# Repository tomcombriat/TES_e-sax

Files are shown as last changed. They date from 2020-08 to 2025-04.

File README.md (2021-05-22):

# TES - e-sax

More infos: https://t-e-s.frama.site/en/tesaxophone

The E-sax is an EWI made out of a real sax. It outputs MIDI signals that can be used to generate sounds using a synthesizer for instance the [10k synth](https://github.com/tomcombriat/TES_10-knobs-synth). It is design to provide saxophone players a digital instrument to which they can transition easily. Additionnaly from the "standard" behavior it also have features that are allowed by a digital instrument:

- EWI mode which tries to give a more ergonomic keying (E mode)
- chords (C mode)
- arpegiators (A and R modes)

## What is in this repo?
The [hardware](hardware/) folder contains the kicad project for the PCB used in the e-sax alongside with the Cu and Fab masks. It is single sided in order to make its construction possible for an hobbyist. Note that the isolations and the routes are fairly small (around 200 microns) so you will need to have a fairly optimized setup to be able to make this PCB correctly.

The [software](software/) folder contains the embedded program that is embedded in the chip. Note that it will need some configurations for any particular saxophone.

The main MCU is a cheap BluePill STM32, programmed using the [Arduino STM32 library](https://github.com/stm32duino/Arduino_Core_STM32) and a FTDI.

## Making
This gives some guidelines in order to allow people to make such an E-sax themselves. It precludes that the PCB is already printed and drilled.

Note: no 3D parts are included in this repo for now. Except for the beak, every part usually need to be redesigned for a different saxophone. Do not hesitate to contact me on that.

### Bill of Materials 

- 24 resistors 1-10k, noted R on the PCB
- 1 resistor 33
- 2 resistors 22k (optionnal)
- 1 resistor 10
- 1 BluePill
- 1 FTDI chip to program the BluePill
- 3 74HC165 Parallel-to-Serial shift registers
- enough header
- 1 SSD1306 Oled screen (*I2C*)
- 1 MPX5010 differential pressure sensor
- 1 joystick with a click
- a good amount of flexible thin wire (around 26 AWG, silicon cover)
- Dupond cables
- a good amount of copper tape
- 1 3-AA battery holder
- 1 MIDI female to solder
- 1 switch (non-momentary)
- 2 pairs (male and female) of JST connectors 3 pins
- 1 pair of JST connectors 5 pins
- 10 magnets (10x4x2mm^3) (optionnal)

### Wiring the saxophone

The controller needs to know what keys are pressed at any given time in order to be able to generate the correct MidiNote for a synthesizer. In order for the behavior to be as close as possible to a real saxophone, the sensors are positionned on the pads and not on the keys: if a key closing a pad is not pressed enough to close the pad the controller will consider it "open" just like it would be for a real saxophone. All the wires for the pads are going through the sax body.

The saxophone is a complex instrument and not every pad can be dismounted "alone": it is usual that some of them need other to be removed first in order to be dismounted.

#### Dismounting
This is why it is usually easier to dismount all the keys first and wire them on remounting.
Note: take some notes about which keys did you dismounted first: as the order matters they will need to be remounted in the _reverse order_. My personnal way of doing it is to write on every part a number and a letter (the latter only if this is a pad): the number denotes the order of dismounting (first dismounted part will be labelled "1", second "2"…) and the letter denotes the hole the pad is covering. I also write the same letter next to, or in, the hole which is covered by the pad. This way, upon remounting, one can start by the part with highest number, spot its hole (if any) and remount it.

#### Wiring the pads

The pads can be wired upon remounting. All pads need to be wired except the one which is just above the left hand forefinger which is not independant from the pad located under the left hand forefinger.

The sensor is composed of a thin copper layer glued to the pad and wire to the PCB. Using a push-up resistor, and by placing the whole sax body at GND the pad will behave as a switch:

- closed, the potential of the copper part will be at GND as it is in contact with the body
- open, the potential will be at 3.3V, thanks to a push-up resistor.

The copper tape needs to be glued to the pad:

- cut a piece of copper tape that matches more or less the dimension of the pad. The exact size of this piece is not critical but:
  - it need to cover some of the parts of the pad which are in contact with the body when closed. If possible at two different locations meaning that the length of this copper part should be at least be equal to the diameter of the hole covered by the pad.
  - it should not be too long either in order not to touch the metallic part of the key.
- apply a thin layer of neopren glue on the **tape** side of the copper, it should cover it all. Beware not to put some glue on the "clear" part of the copper
- apply a thin layer of neopren on the pad, it should match the dimensions of the piece of copper.
- wait from 10 to 15 minutes
- apply the copper, glue side of the tape facing the glue side of the pad, it should stick immediatly so the first attempt should be well positionned.
- using a soldering iron, add some solder at **the middle of the pad**, it should not touch the part where the pad touches the body.
- soldier a flexible wire long enough to go from the corresponding hole to the bell plus 5cm to it.
- put the wire in the hole and make it go to the bell throught the body (this can be hard for some keys) and tape it to the bell.
- remount the key on its hole.
- if done correctly, the key should action seemlessly and feel as natural as before.
- start again for all the other keys.

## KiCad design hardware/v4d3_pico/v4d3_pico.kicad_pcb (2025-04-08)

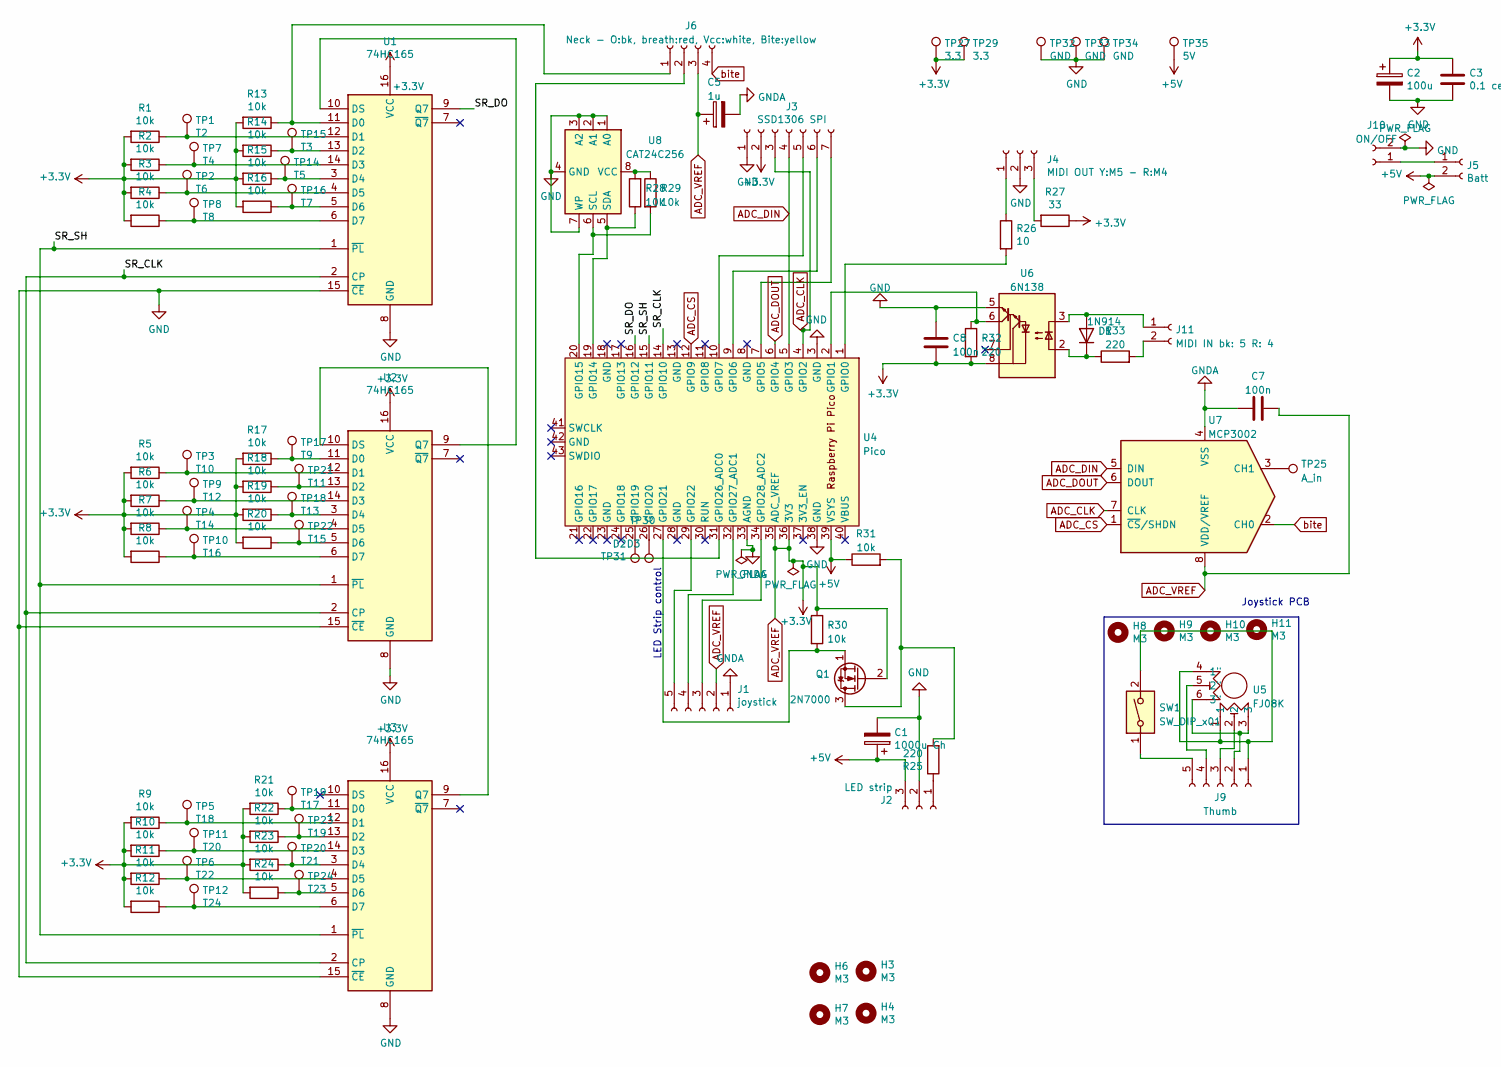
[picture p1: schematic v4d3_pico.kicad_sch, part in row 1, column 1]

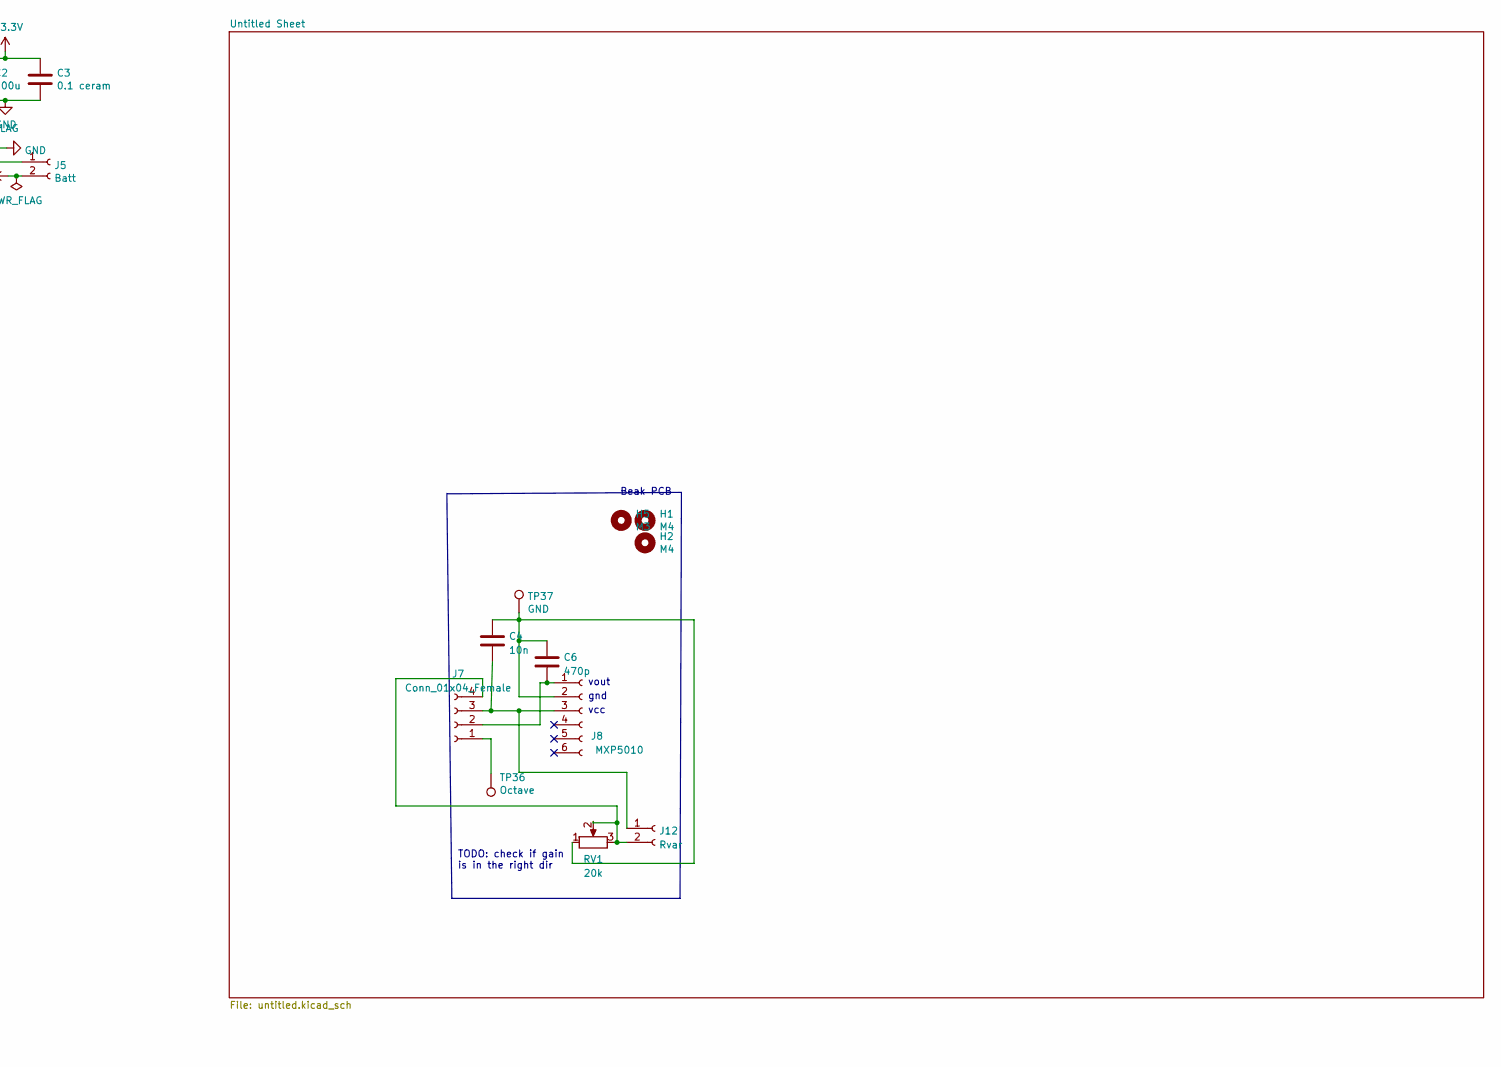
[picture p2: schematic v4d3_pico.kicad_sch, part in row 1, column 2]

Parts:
C1: 1000u Ch; CP_Radial_D8.0mm_P3.50mm
C2: 100u; CP_Radial_D5.0mm_P2.50mm
C3: 0.1 ceram; C_Disc_D3.4mm_W2.1mm_P2.50mm
C4: 10n; C_Disc_D3.4mm_W2.1mm_P2.50mm
C5: 1u; CP_Radial_D4.0mm_P2.00mm
C6: 470p; C_Disc_D3.4mm_W2.1mm_P2.50mm
C7, C8: 100n; C_Axial_L3.8mm_D2.6mm_P7.50mm_Horizontal
D1: 1N914; D_DO-34_SOD68_P7.62mm_Horizontal
H1, H2: M4; MountingHole_4.3mm_M4
H3, H4, H5, H6, H7, H8, H9, H10, H11: M3; MountingHole_3.2mm_M3_ISO14580
J1: joystick; JST_PH_B5B-PH-K_1x05_P2.00mm_Vertical
J2: LED strip; JST_PH_S3B-PH-K_1x03_P2.00mm_Horizontal
J3: SSD1306 SPI; JST_PH_B7B-PH-K_1x07_P2.00mm_Vertical
J4: MIDI OUT Y:M5 - R:M4; JST_PH_S3B-PH-K_1x03_P2.00mm_Horizontal
J5: Batt; JST_XH_S2B-XH-A_1x02_P2.50mm_Horizontal
J6: Neck - O:bk, breath:red, Vcc:white, Bite:yellow; JST_PH_B4B-PH-K_1x04_P2.00mm_Vertical
J7: Conn_01x04_Female; JST_PH_B4B-PH-K_1x04_P2.00mm_Vertical
J8: MXP5010; PinSocket_1x06_P2.54mm_Vertical
J9: Thumb; JST_PH_S5B-PH-K_1x05_P2.00mm_Horizontal
J10: ON/OFF; JST_XH_S2B-XH-A_1x02_P2.50mm_Horizontal
J11: MIDI IN bk: 5 R: 4; JST_XH_S2B-XH-A_1x02_P2.50mm_Horizontal
J12: Rvar; JST_XH_B2B-XH-A_1x02_P2.50mm_Vertical
Q1: 2N7000; TO-92L_HandSolder
R1, R2, R3, R4, R5, R6, R7, R8, R9, R10, R11, R12, R13, R14, R15, R16, R17, R18, R19, R20, R21, R22, R23, R24, R28, R29, R30: 10k; R_1206_3216Metric_Pad1.30x1.75mm_HandSolder
R25, R32, R33: 220; R_Axial_DIN0207_L6.3mm_D2.5mm_P7.62mm_Horizontal
R26: 10; R_Axial_DIN0207_L6.3mm_D2.5mm_P7.62mm_Horizontal
R27: 33; R_Axial_DIN0207_L6.3mm_D2.5mm_P7.62mm_Horizontal
R31: 10k; R_Axial_DIN0207_L6.3mm_D2.5mm_P7.62mm_Horizontal
RV1: 20k; Potentiometer_Runtron_RM-065_Vertical
SW1: SW_DIP_x01; Multi_switch
TP1: T2; TestPoint_THTPad_2.5x2.5mm_Drill1.2mm
TP2: T6; TestPoint_THTPad_2.5x2.5mm_Drill1.2mm
TP3: T10; TestPoint_THTPad_2.5x2.5mm_Drill1.2mm
TP4: T14; TestPoint_THTPad_2.5x2.5mm_Drill1.2mm
TP5: T18; TestPoint_THTPad_2.5x2.5mm_Drill1.2mm
TP6: T22; TestPoint_THTPad_2.5x2.5mm_Drill1.2mm
TP7: T4; TestPoint_THTPad_2.5x2.5mm_Drill1.2mm
TP8: T8; TestPoint_THTPad_2.5x2.5mm_Drill1.2mm
TP9: T12; TestPoint_THTPad_2.5x2.5mm_Drill1.2mm
TP10: T16; TestPoint_THTPad_2.5x2.5mm_Drill1.2mm
TP11: T20; TestPoint_THTPad_2.5x2.5mm_Drill1.2mm
TP12: T24; TestPoint_THTPad_2.5x2.5mm_Drill1.2mm
TP14: T5; TestPoint_THTPad_2.5x2.5mm_Drill1.2mm
TP15: T3; TestPoint_THTPad_2.5x2.5mm_Drill1.2mm
TP16: T7; TestPoint_THTPad_2.5x2.5mm_Drill1.2mm
TP17: T9; TestPoint_THTPad_2.5x2.5mm_Drill1.2mm
TP18: T13; TestPoint_THTPad_2.5x2.5mm_Drill1.2mm
TP19: T17; TestPoint_THTPad_2.5x2.5mm_Drill1.2mm
TP20: T21; TestPoint_THTPad_2.5x2.5mm_Drill1.2mm
TP21: T11; TestPoint_THTPad_2.5x2.5mm_Drill1.2mm
TP22: T15; TestPoint_THTPad_2.5x2.5mm_Drill1.2mm
TP23: T19; TestPoint_THTPad_2.5x2.5mm_Drill1.2mm
TP24: T23; TestPoint_THTPad_2.5x2.5mm_Drill1.2mm
TP25: A_in; TestPoint_THTPad_2.5x2.5mm_Drill1.2mm
TP27, TP29: 3.3; TestPoint_THTPad_2.5x2.5mm_Drill1.2mm
TP30: D3; TestPoint_THTPad_2.5x2.5mm_Drill1.2mm
TP31: D2; TestPoint_THTPad_2.5x2.5mm_Drill1.2mm
TP32, TP33, TP34, TP37: GND; TestPoint_THTPad_2.5x2.5mm_Drill1.2mm
TP35: 5V; TestPoint_THTPad_2.5x2.5mm_Drill1.2mm
TP36: Octave; TestPoint_THTPad_2.5x2.5mm_Drill1.2mm
U1, U2, U3: 74HC165; SOIC-16_3.9x9.9mm_P1.27mm
U4: Pico; RPi_Pico_TH
U5: FJ08K
U6: 6N138; DIP-8_W7.62mm_Socket
U7: MCP3002; DIP-8_W7.62mm
U8: CAT24C256; DIP-8_W7.62mm_Socket

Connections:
+5V: C1.1, J2.3, J5.2, R31.1, TP35.1, U4.39 (VSYS)
/SR_CLK: U1.2 (CP), U2.2 (CP), U3.2 (CP), U4.14 (GPIO10)
/SR_DO: U1.9 (Q7), U4.16 (GPIO12)
/SR_SH: U1.1 (~PL), U2.1 (~PL), U3.1 (~PL), U4.15 (GPIO11)
ADC_CLK: J3.3, U4.4 (GPIO2), U7.7 (CLK)
ADC_CS: U4.12 (GPIO9), U7.1 (~CS/SHDN)
ADC_DIN: J3.4, U4.5 (GPIO3), U7.5 (DIN)
ADC_DOUT: U4.6 (GPIO4), U7.6 (DOUT)
ADC_VREF: C2.1, C3.1, C5.1, C7.2, C8.2, J1.2, J3.2, J6.3, Q1.2 (G), R1.2, R2.2, R3.2, R4.2, R5.2, R6.2, R7.2, R8.2, R9.2, R10.2, R11.2, R12.2, R13.2, R14.2, R15.2, R16.2, R17.2, R18.2, R19.2, R20.2, R21.2, R22.2, R23.2, R24.2, R27.1, R30.1, R32.2, TP27.1, TP29.1, U1.16 (VCC), U2.16 (VCC), U3.16 (VCC), U4.35 (ADC_VREF), U4.36 (3V3), U6.8 (VCC), U7.8 (VDD/VREF)
GND: C1.2, C2.2, C3.2, C8.1, J2.2, J3.1, J4.2, J10.2, TP32.1, TP33.1, TP34.1, U1.8 (GND), U1.15 (~CE), U2.8 (GND), U2.15 (~CE), U3.8 (GND), U3.15 (~CE), U4.3 (GND), U4.38 (GND), U6.5 (GND), U8.1 (A0), U8.2 (A1), U8.3 (A2), U8.4 (GND), U8.7 (WP)
GNDA: C5.2, C7.1, J1.1, U4.33 (AGND), U7.4 (VSS)
unnamed: C4.2, J7.3, J8.3, J12.1
unnamed: C6.2, J7.2, J8.1
unnamed: D1.1 (K), R33.1, U6.2 (C1)
unnamed: D1.2 (A), J11.1, U6.3 (C2)
unnamed: J1.3, U4.34 (GPIO28_ADC2)
unnamed: J1.4, U4.32 (GPIO27_ADC1)
unnamed: J1.5, U4.29 (GPIO22)
unnamed: J2.1, R25.1
unnamed: J3.5, U4.10 (GPIO7)
unnamed: J3.6, U4.9 (GPIO6)
unnamed: J3.7, U4.7 (GPIO5)
unnamed: J4.1, R26.1
unnamed: J4.3, R27.2
unnamed: J6.1, R13.1, U1.11 (D0)
unnamed: J6.2, U4.31 (GPIO26_ADC0)
unnamed: J7.1, TP36.1
unnamed: J9.1, SW1.2, U5.1, U5.4 (1")
unnamed: J9.2, U5.3, U5.6 (3")
unnamed: J9.3, U5.2
unnamed: J9.4, U5.5 (2")
unnamed: J9.5, SW1.1
unnamed: J5.1, J10.1
unnamed: J11.2, R33.2
unnamed: Q1.1 (S), R30.2, U4.27 (GPIO21)
unnamed: Q1.3 (D), R25.2, R31.2
unnamed: R1.1, TP1.1, U1.12 (D1)
unnamed: R2.1, TP7.1, U1.14 (D3)
unnamed: R3.1, TP2.1, U1.4 (D5)
unnamed: R4.1, TP8.1, U1.6 (D7)
unnamed: R5.1, TP3.1, U2.12 (D1)
unnamed: R6.1, TP9.1, U2.14 (D3)
unnamed: R7.1, TP4.1, U2.4 (D5)
unnamed: R8.1, TP10.1, U2.6 (D7)
unnamed: R9.1, TP5.1, U3.12 (D1)
unnamed: R10.1, TP11.1, U3.14 (D3)
unnamed: R11.1, TP6.1, U3.4 (D5)
unnamed: R12.1, TP12.1, U3.6 (D7)
unnamed: R14.1, TP15.1, U1.13 (D2)
unnamed: R15.1, TP14.1, U1.3 (D4)
unnamed: R16.1, TP16.1, U1.5 (D6)
unnamed: R17.1, TP17.1, U2.11 (D0)
unnamed: R18.1, TP21.1, U2.13 (D2)
unnamed: R19.1, TP18.1, U2.3 (D4)
unnamed: R20.1, TP22.1, U2.5 (D6)
unnamed: R21.1, TP19.1, U3.11 (D0)
unnamed: R22.1, TP23.1, U3.13 (D2)
unnamed: R23.1, TP20.1, U3.3 (D4)
unnamed: R24.1, TP24.1, U3.5 (D6)
unnamed: R26.2, U4.1 (GPIO0)
unnamed: R28.1, U4.19 (GPIO14), U8.5 (SDA)
unnamed: R28.2, R29.1, U8.8 (VCC)
unnamed: R29.2, U4.20 (GPIO15), U8.6 (SCL)
unnamed: R32.1, U4.2 (GPIO1), U6.6 (VO2)
unnamed: TP25.1, U7.3 (CH1)
unnamed: TP30.1, U4.26 (GPIO20)
unnamed: TP31.1, U4.25 (GPIO19)
unnamed: U1.10 (DS), U2.9 (Q7)
unnamed: U2.10 (DS), U3.9 (Q7)
bite: J6.4, U7.2 (CH0)

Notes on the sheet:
vcc
TODO: check if gain is in the right dir
gnd
Joystick PCB
vout
Beak PCB
LED Strip control

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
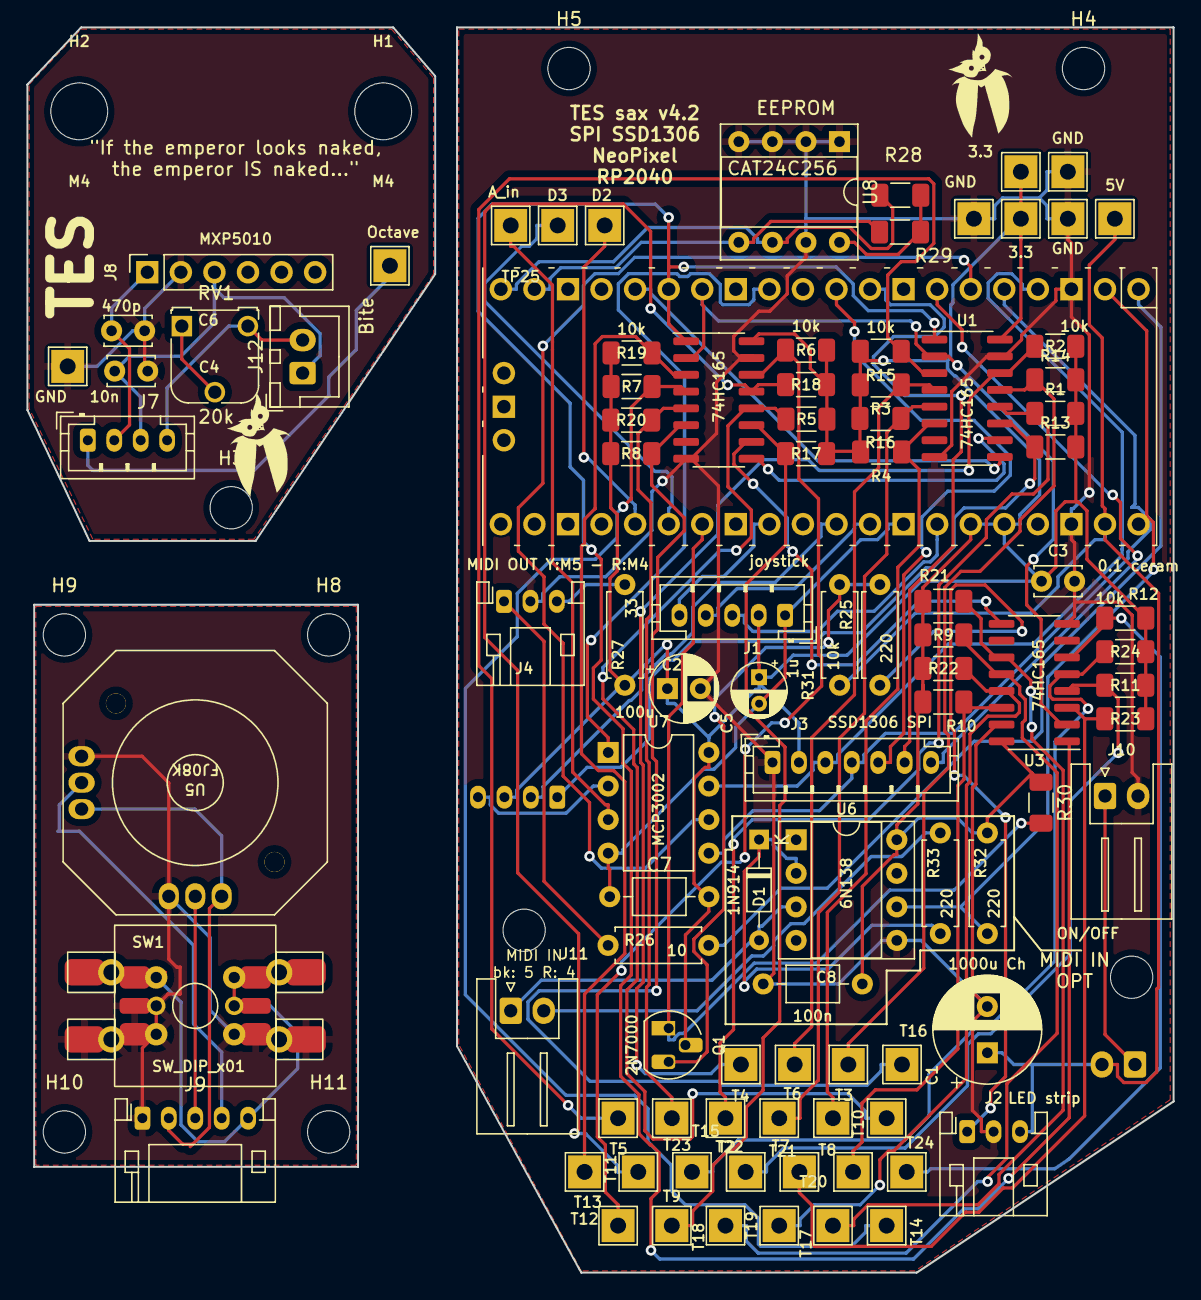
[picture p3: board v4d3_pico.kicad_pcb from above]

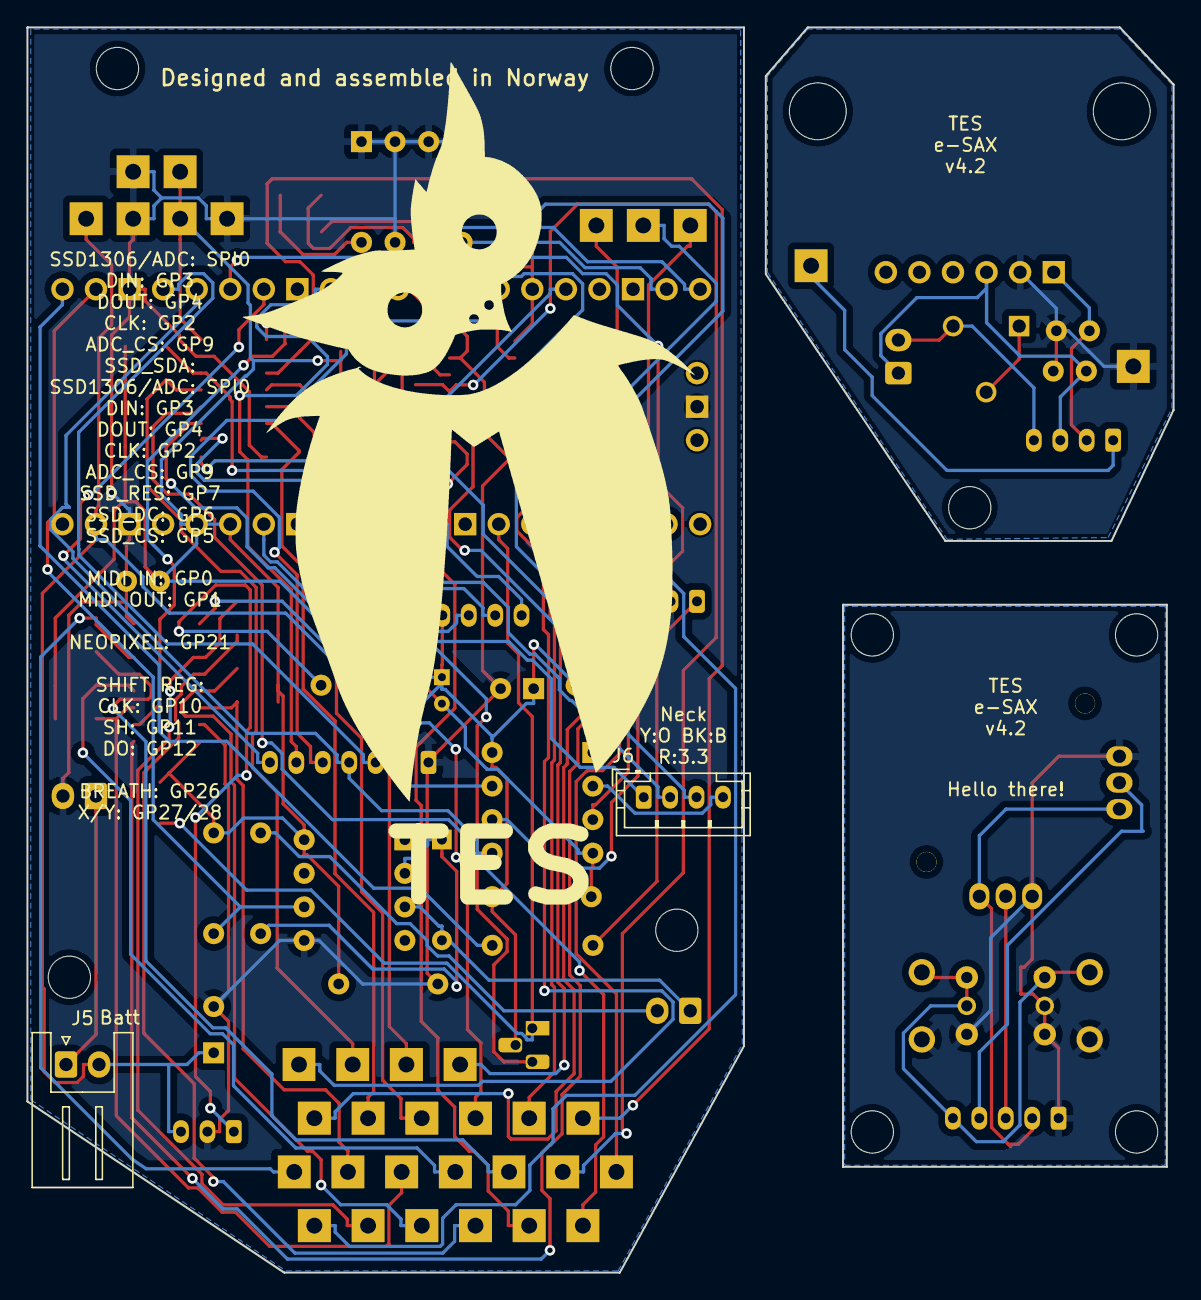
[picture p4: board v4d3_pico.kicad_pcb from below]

Board: 2 copper layers, 86.7 x 94.2 mm, 113 parts (3 on the bottom side), 73 nets.

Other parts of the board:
owl_beak: LOGO; owl_7x10
owl_big_pcb: LOGO; owl_F_50x70
owl_small_pcb: LOGO; owl_7x10

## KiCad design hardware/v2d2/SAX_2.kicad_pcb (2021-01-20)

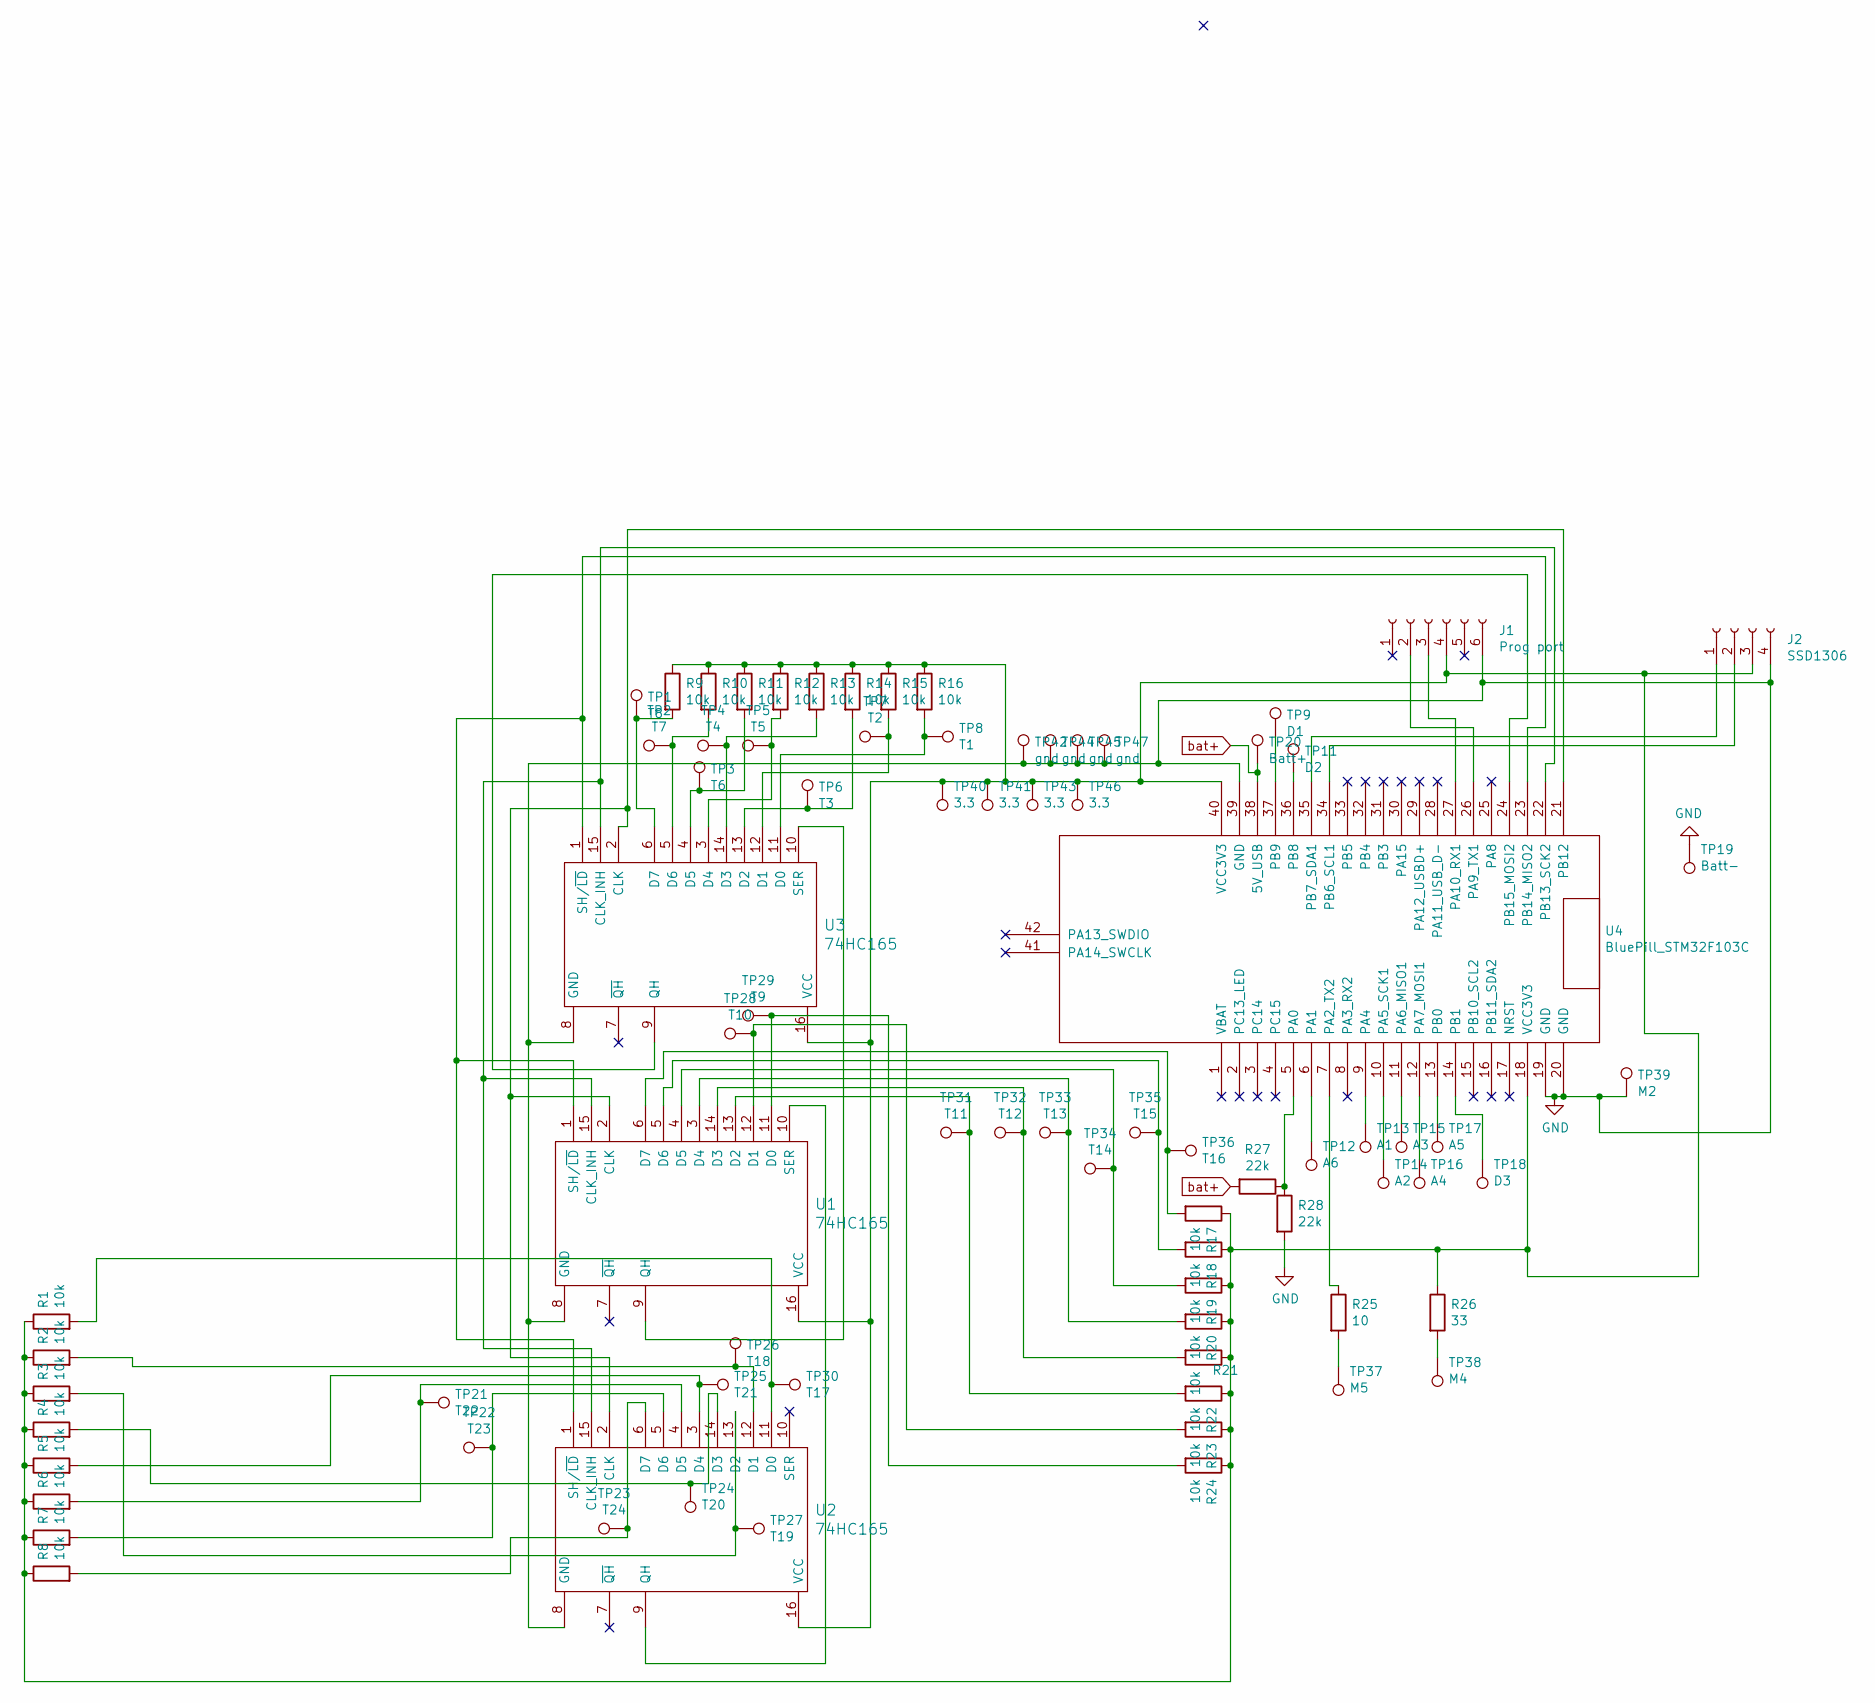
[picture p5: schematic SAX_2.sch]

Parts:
J1: Prog port; PinSocket_1x06_P2.54mm_Vertical
J2: SSD1306; PinSocket_1x04_P2.54mm_Vertical
R1, R2, R3, R4, R5, R6, R7, R8, R9, R10, R11, R12, R13, R14, R15, R16, R17, R18, R19, R20, R21, R22, R23, R24: 10k; R_Axial_DIN0207_L6.3mm_D2.5mm_P7.62mm_Horizontal
R25: 10; R_Axial_DIN0207_L6.3mm_D2.5mm_P7.62mm_Horizontal
R26: 33; R_Axial_DIN0207_L6.3mm_D2.5mm_P7.62mm_Horizontal
R27, R28: 22k; R_Axial_DIN0207_L6.3mm_D2.5mm_P7.62mm_Horizontal
TP1: T8; TestPoint_THTPad_D2.0mm_Drill1.0mm
TP2: T7; TestPoint_THTPad_D2.0mm_Drill1.0mm
TP3: T6; TestPoint_THTPad_D2.0mm_Drill1.0mm
TP4: T4; TestPoint_THTPad_D2.0mm_Drill1.0mm
TP5: T5; TestPoint_THTPad_D2.0mm_Drill1.0mm
TP6: T3; TestPoint_THTPad_D2.0mm_Drill1.0mm
TP7: T2; TestPoint_THTPad_D2.0mm_Drill1.0mm
TP8: T1; TestPoint_THTPad_D2.0mm_Drill1.0mm
TP9: D1; TestPoint_THTPad_D2.0mm_Drill1.0mm
TP11: D2; TestPoint_THTPad_D2.0mm_Drill1.0mm
TP12: A6; TestPoint_THTPad_D2.0mm_Drill1.0mm
TP13: A1; TestPoint_THTPad_D2.0mm_Drill1.0mm
TP14: A2; TestPoint_THTPad_D2.0mm_Drill1.0mm
TP15: A3; TestPoint_THTPad_D2.0mm_Drill1.0mm
TP16: A4; TestPoint_THTPad_D2.0mm_Drill1.0mm
TP17: A5; TestPoint_THTPad_D2.0mm_Drill1.0mm
TP18: D3; TestPoint_THTPad_D2.0mm_Drill1.0mm
TP19: Batt-; TestPoint_THTPad_D2.0mm_Drill1.0mm
TP20: Batt+; TestPoint_THTPad_D2.0mm_Drill1.0mm
TP21: T22; TestPoint_THTPad_D2.0mm_Drill1.0mm
TP22: T23; TestPoint_THTPad_D2.0mm_Drill1.0mm
TP23: T24; TestPoint_THTPad_D2.0mm_Drill1.0mm
TP24: T20; TestPoint_THTPad_D2.0mm_Drill1.0mm
TP25: T21; TestPoint_THTPad_D2.0mm_Drill1.0mm
TP26: T18; TestPoint_THTPad_D2.0mm_Drill1.0mm
TP27: T19; TestPoint_THTPad_D2.0mm_Drill1.0mm
TP28: T10; TestPoint_THTPad_D2.0mm_Drill1.0mm
TP29: T9; TestPoint_THTPad_D2.0mm_Drill1.0mm
TP30: T17; TestPoint_THTPad_D2.0mm_Drill1.0mm
TP31: T11; TestPoint_THTPad_D2.0mm_Drill1.0mm
TP32: T12; TestPoint_THTPad_D2.0mm_Drill1.0mm
TP33: T13; TestPoint_THTPad_D2.0mm_Drill1.0mm
TP34: T14; TestPoint_THTPad_D2.0mm_Drill1.0mm
TP35: T15; TestPoint_THTPad_D2.0mm_Drill1.0mm
TP36: T16; TestPoint_THTPad_D2.0mm_Drill1.0mm
TP37: M5; TestPoint_THTPad_D2.0mm_Drill1.0mm
TP38: M4; TestPoint_THTPad_D2.0mm_Drill1.0mm
TP39: M2; TestPoint_THTPad_D2.0mm_Drill1.0mm
TP40, TP41, TP43, TP46: 3.3; TestPoint_THTPad_D2.0mm_Drill1.0mm
TP42, TP44, TP45, TP47: gnd; TestPoint_THTPad_D2.0mm_Drill1.0mm
U1, U2, U3: 74HC165; DIP-16_W7.62mm
U4: BluePill_STM32F103C

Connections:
GND: J1.6, J2.4, R28.2, TP19.1, TP39.1, TP42.1, TP44.1, TP45.1, TP47.1, U1.8 (GND), U2.8 (GND), U3.8 (GND), U4.19 (GND), U4.20 (GND), U4.39 (GND)
unnamed: J1.2, U4.26 (PA9_TX1)
unnamed: J1.3, U4.27 (PA10_RX1)
unnamed: J1.4, J2.3, R1.1, R2.1, R3.1, R4.1, R5.1, R6.1, R7.1, R8.1, R9.1, R10.1, R11.1, R12.1, R13.1, R14.1, R15.1, R16.1, R17.1, R18.1, R19.1, R20.1, R21.1, R22.1, R23.1, R24.1, R26.1, TP40.1, TP41.1, TP43.1, TP46.1, U1.16 (VCC), U2.16 (VCC), U3.16 (VCC), U4.18 (VCC3V3), U4.40 (VCC3V3)
unnamed: J2.1, U4.35 (PB7_SDA1)
unnamed: J2.2, U4.34 (PB6_SCL1)
unnamed: R1.2, TP30.1, U2.11 (D0)
unnamed: R2.2, TP26.1, U2.12 (D1)
unnamed: R3.2, TP27.1, U2.13 (D2)
unnamed: R4.2, TP24.1, U2.14 (D3)
unnamed: R5.2, TP25.1, U2.3 (D4)
unnamed: R6.2, TP21.1, U2.4 (D5)
unnamed: R7.2, TP22.1, U2.5 (D6)
unnamed: R8.2, TP23.1, U2.6 (D7)
unnamed: R9.2, TP1.1, U3.6 (D7)
unnamed: R10.2, TP2.1, U3.5 (D6)
unnamed: R11.2, TP3.1, U3.4 (D5)
unnamed: R12.2, TP5.1, U3.3 (D4)
unnamed: R13.2, TP4.1, U3.14 (D3)
unnamed: R14.2, TP6.1, U3.13 (D2)
unnamed: R15.2, TP7.1, U3.12 (D1)
unnamed: R16.2, TP8.1, U3.11 (D0)
unnamed: R17.2, TP36.1, U1.6 (D7)
unnamed: R18.2, TP35.1, U1.5 (D6)
unnamed: R19.2, TP34.1, U1.4 (D5)
unnamed: R20.2, TP33.1, U1.3 (D4)
unnamed: R21.2, TP32.1, U1.14 (D3)
unnamed: R22.2, TP31.1, U1.13 (D2)
unnamed: R23.2, TP28.1, U1.12 (D1)
unnamed: R24.2, TP29.1, U1.11 (D0)
unnamed: R25.1, U4.7 (PA2_TX2)
unnamed: R25.2, TP37.1
unnamed: R26.2, TP38.1
unnamed: R27.1, R28.1, U4.5 (PA0)
unnamed: TP9.1, U4.37 (PB9)
unnamed: TP11.1, U4.36 (PB8)
unnamed: TP12.1, U4.6 (PA1)
unnamed: TP13.1, U4.9 (PA4)
unnamed: TP14.1, U4.10 (PA5_SCK1)
unnamed: TP15.1, U4.11 (PA6_MISO1)
unnamed: TP16.1, U4.12 (PA7_MOSI1)
unnamed: TP17.1, U4.13 (PB0)
unnamed: TP18.1, U4.14 (PB1)
unnamed: U1.1 (SH/~LD), U2.1 (SH/~LD), U3.1 (SH/~LD), U4.23 (PB14_MISO2)
unnamed: U1.2 (CLK), U2.2 (CLK), U3.2 (CLK), U4.21 (PB12)
unnamed: U1.9 (QH), U3.10 (SER)
unnamed: U1.10 (SER), U2.9 (QH)
unnamed: U1.15 (CLK_INH), U2.15 (CLK_INH), U3.15 (CLK_INH), U4.22 (PB13_SCK2)
unnamed: U3.9 (QH), U4.24 (PB15_MOSI2)
bat+: R27.2, TP20.1, U4.38 (5V_USB)

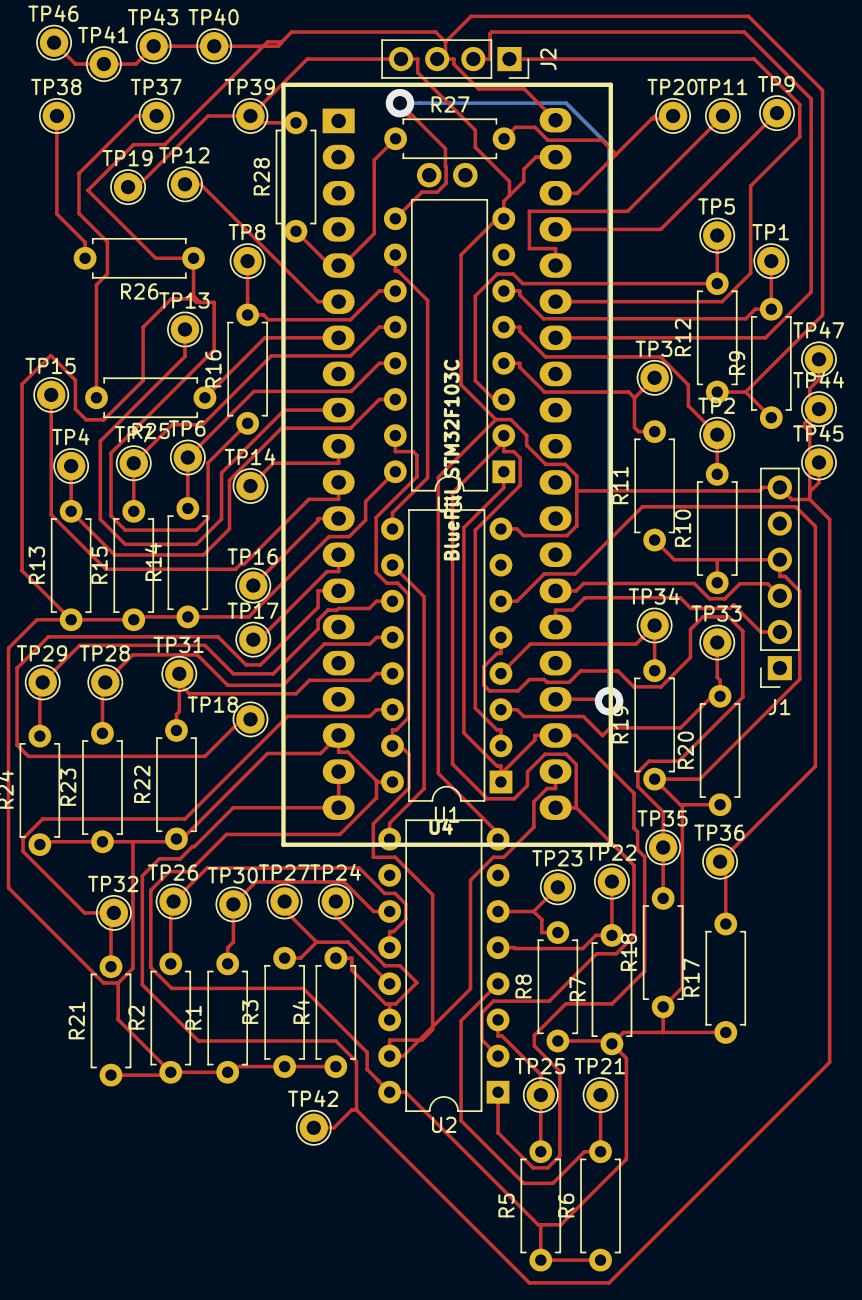
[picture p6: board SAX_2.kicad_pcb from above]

Board: 2 copper layers, 80 parts (0 on the bottom side), 50 nets.

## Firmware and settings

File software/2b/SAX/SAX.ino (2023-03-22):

/*
      Combriat 2018, 2019, 2020, 2021
      This file is part of the OS embedded in the e-sax SN4 - TES
      This code is under GPL3
      This is the main program. To be compiled in O2
*/



#include <SPI.h>
#include <Wire.h>
#include <Adafruit_GFX.h>
#include <Adafruit_SSD1306.h>
#include <Adafruit_NeoPixel.h>
#include <MIDI.h>





#include "analog_input.h"
#include "button.h"
#include "read_shift_reg.h"
#include "note_manager.h"
#include "midi_cc.h"
#include "screen.h"
#include "menu.h"
#include "tap_tempo.h"
#include "arpegio_mono.h"
#include "chord.h"
#include "pitchbend.h"
#include "presets.h"
#include "battery.h"
#include "curved_analog_input.h"
#include "LEDstrand.h"




/***************************/
/******* DEFINE ************/
/***************************/

// Screen
#define OLED_DC     6
#define OLED_CS     4
#define OLED_RESET  12

// Strand
#define DATA_PIN 23

#define SUB_MODIFIER_RESPONSE_TIME 20
#define MODIFIER_RESPONSE_TIME 20
#define JOYSTICK_RESPONSE_TIME 10
#define JOYSTICK_SAFETY 30
#define JOYSTICK_DEAD_ZONE 10
#define BATTERY_RESPONSE_TIME 3000
#define BREATH_RESPONSE_TIME 1
#define CC_DELTA_TIME 40
#define CC_MIN_TIME 5
#define PITCHBEND_MIN_TIME 10
#define SCREEN_UPDATE_TIME 20
#define SCREEN_IDLE_WAITING_TIME 400
#define STRAND_RESPONSE_TIME 20
#define BATT_PIN A7
#define BREATH_THRESHOLD 1.1




Adafruit_SSD1306 display(128, 64, &SPI, OLED_DC, OLED_RESET, OLED_CS);
Adafruit_NeoPixel strip(NUM_LEDS, DATA_PIN, NEO_GRBW + NEO_KHZ800);


/*
  #define MODE_EWI 0
  #define MODE_ARPEGIO 1
  #define MODE_CHORD 2
  #define MODE_ARPEGIO_RAND 3*/

enum modes {MODE_NORMAL, MODE_EWI, MODE_ARPEGIO, MODE_CHORD, MODE_ARPEGIO_RAND};
//enum chord_modes {REPLACE, STACK};
char global_modes[5] = {'N', 'E', 'A', 'C', 'R'};


#define JOY_BASE_TARGET_RANGE 127
#define JOY_PB_TARGET_RANGE 8192



/***************************/
/****** ANALOG INPUTS ******/
/***************************/
analog_input joy_Y(A4, 0, JOYSTICK_RESPONSE_TIME);
analog_input joy_X(A3, 0, JOYSTICK_RESPONSE_TIME);
//analog_input breath(PA1, 0, BREATH_RESPONSE_TIME, 20);
curved_analog_input breath(A5, 4055 * 2, 0, BREATH_RESPONSE_TIME, 7, 7);


/***************************/
/********* BUTTONS *********/
/***************************/
button joy_SW(16, false, JOYSTICK_RESPONSE_TIME);
button octave(-1, true, MODIFIER_RESPONSE_TIME);
button modifier_up(-1, true, MODIFIER_RESPONSE_TIME);
button modifier_mid(-1, true, MODIFIER_RESPONSE_TIME);
button modifier_down(-1, true, MODIFIER_RESPONSE_TIME);
button modifier_sub_up(-1, true, SUB_MODIFIER_RESPONSE_TIME);
button modifier_sub_down(-1, true, SUB_MODIFIER_RESPONSE_TIME);
button up_menu(-1, true, SUB_MODIFIER_RESPONSE_TIME);
button down_menu(-1, true, SUB_MODIFIER_RESPONSE_TIME);
button right_menu(-1, true, SUB_MODIFIER_RESPONSE_TIME);
button left_menu(-1, true, SUB_MODIFIER_RESPONSE_TIME);
button *modifiers[3] = {&modifier_up, &modifier_mid, &modifier_down};
button up_preset (-1, true, SUB_MODIFIER_RESPONSE_TIME);
button down_preset (-1, true, SUB_MODIFIER_RESPONSE_TIME);

//mettre up down et right left


/*************************/
/****** NOTE MANAGER *****/
/************************/
note_manager manager;




/*************************/
/***** SCREEN ************/
/*************************/
screen ssd;
unsigned long stop_played_time = 0;


/****************************/
/******* MIDI ***************/
/****************************/
MIDI_CREATE_INSTANCE(HardwareSerial, Serial1, MIDI);
byte midi_channel = 2, midi_channel_chords = 3;
int8_t midi_transpose = 0;
int8_t midi_octave = 0;




/****************************/
/******* STATE **************/
/****************************/
bool delta_mode = true;
byte global_mode = MODE_NORMAL;
bool played = false;
bool pitchbend_enable = false;
bool dynamic_velocity = true;
bool HQ_breath = false;
bool replacing_chord = true;
bool LED_mode = true;





/************************/
/***** MIDI CC **********/
/************************/
midi_cc X_CC(71, 64);
midi_cc Y_CC(1, 64);
midi_cc breath_CC(74);
midi_cc breath_LSB_CC(75);
midi_cc pitchbend_amp_CC(5);


/************************/
/****** TEMPO ***********/
/************************/
tap_tempo tap;



/************************/
/******** ARPS **********/
/************************/
arpegio_mono arp[3];
uint8_t selected_arp[3] = {0, 1, 2};



/************************/
/****** CHORD ***********/
/************************/
chord chords[3];
uint8_t selected_chord[3] = {0, 1, 2};


/************************/
/****** PITCHBEND *******/
/************************/
pitchbend PB;



/****************************/
/** NORMAL MODE MODIFIERS ***/
/****************************/
int8_t normal_up_modifier = +1;
int8_t normal_mid_modifier = -1;
int8_t normal_down_modifier = +7;





/*****************************/
/**** BATTERY ****************/
/*****************************/
battery batt(BATT_PIN, 2360, 3200, BATTERY_RESPONSE_TIME);

/*****************************
   STRAND
*/
LEDstrand strand;


void setup() {
  display.begin(SSD1306_SWITCHCAPVCC);

  analogReadResolution(12);
  //Serial.begin(115200);


  pinMode(BATT_PIN, INPUT);
  delay(20);
  display.clearDisplay();
  display.setCursor(30, 15);
  display.setTextColor(1, 0);
  display.setTextSize(4);
  display.print("TES");
  display.setCursor(35, 50);
  display.setTextSize(2);
  display.print("e-Sax");
  display.display();
  strip.begin();  // initialize strip (required!)
  strand.splash();
  //delay(200);
  for (int i = 0; i < 3; i++) arp[i].set_notes(arp_N[i], arp_times[i], arp_notes[i], arp_name[i], arp_long_names[i]);
  for (int i = 0; i < 3; i++) chords[i].set_notes(chord_N[i], chord_notes[i], chord_name[i], chord_long_names[i]);


  //joy_X.set_invert(true);
  //joy_Y.set_invert(true);
  joy_X.calibrate();
  joy_Y.calibrate();
  breath.calibrate();
  get_joy_input_ranges();
  joy_X.set_min_max(-127, 127);
  joy_Y.set_min_max(-127, 127);
  breath.set_min_max(0, 16383);

  display.setRotation(2);

  MIDI.begin(MIDI_CHANNEL_OMNI);
  pitchbend_amp_CC.set_value(2);
  pitchbend_amp_CC.update();


  batt.update();
  //batt.display_percentage();
  //eeprom_init();  // On first loading of this code only for teensy
  // TESTING
  display.clearDisplay();
  display.setCursor(30, 15);
  display.print(analogRead(BATT_PIN));
  display.display();

  preset_recall(0);
  delay(500);
  joy_X.calibrate();
  joy_Y.calibrate();
  breath.calibrate();
  //MIDI.sendRealTime(midi::Clock);

  for (int i = 0; i < NUM_LEDS; i++) strip.setPixelColor(i, strip.ColorHSV(47000));
  strip.show();


}

void loop() {


  if ((!played && millis() - stop_played_time > SCREEN_IDLE_WAITING_TIME) )
  {
    ssd.draw_standby_screen(midi_octave, midi_transpose, global_mode, delta_mode, X_CC.get_value(), Y_CC.get_value(), tap.get_tempo());
    ssd.update();
  }

  joy_SW.update();
  octave.update();
  modifier_up.update();
  modifier_mid.update();
  modifier_down.update();
  modifier_sub_up.update();
  modifier_sub_down.update();
  breath.update();
  joy_X.update();
  joy_Y.update();
  breath_CC.update();
  batt.update();
  up_preset.update();
  down_preset.update();
  if (LED_mode)  strand.update();

  /*
    Serial.print(analogRead(A4));
    Serial.print(" ");
    Serial.print(joy_Y.up_down());
    Serial.print(" ");
    Serial.print(joy_X.up_down());
    Serial.print(" ");
    Serial.println(analogRead(A3));
  */

  // Serial.println(breath.value());
  if ((global_mode == MODE_ARPEGIO || global_mode == MODE_ARPEGIO_RAND) && tap.has_change())  for (byte i = 0; i < 3; i++)  arp[i].set_tempo(tap.get_tempo_time());   // update tempo of arpegiators


  /***********************************
     NEW NOTE
   ***********************************/
  if (manager.update())   // different note has been detected
  {

    if (manager.get_previous_note()[0] != 0 && played)    //already played but different note -> shutdown previous note
    {
      for (byte i = 0; i < POLYPHONY; i++)
      {
        if (manager.get_previous_note()[i] != 0 && manager.get_previous_note()[i] != manager.get_note()[i])
        {
          if (i) MIDI.sendNoteOff(manager.get_previous_note()[i], 0, midi_channel_chords);
          else MIDI.sendNoteOff(manager.get_previous_note()[i], 0, midi_channel);
        }
      }
      played = false;
      stop_played_time = millis();
    }

    if (manager.get_note()[0] != 0 && breath.value() > 0)   // new note is playable  -> play it
    {
      byte vel = 127;
      if (dynamic_velocity) vel = breath.MSB();
      played = true;
      for (byte i = 0; i < POLYPHONY; i++)
      {
        if (manager.get_note()[i] != 0 && manager.get_previous_note()[i] != manager.get_note()[i])
        {
          if (i) MIDI.sendNoteOn(manager.get_note()[i], vel, midi_channel_chords);
          else MIDI.sendNoteOn(manager.get_note()[i], vel, midi_channel);
        }

      }
    }
  }  // end of   «if (manager.update())»





  if (breath.value() > 0 && !played && manager.get_note()[0] != 0)    // breath is loud enough to play note
  {
    byte vel = 127;
    if (dynamic_velocity) vel = breath.MSB();

    for (byte i = 0; i < POLYPHONY; i++)
    {
      if (manager.get_note()[i] != 0)
      {
        if (i) MIDI.sendNoteOn(manager.get_note()[i], vel, midi_channel_chords);
        else MIDI.sendNoteOn(manager.get_note()[i], vel, midi_channel);
      }
      //else break;
    }
    played = true;
    if (global_mode == MODE_ARPEGIO || global_mode == MODE_ARPEGIO_RAND)
    {
      int last_in_arp = -1;
      unsigned long last_time = 0;
      for (byte i = 0; i < 3; i++)
      {
        if (modifiers[i]->is_pressed() && modifiers[i]->get_last_press_time() > last_time)
        {
          last_time = modifiers[i]->get_last_press_time();
          last_in_arp = i;
        }
      }
      if (last_in_arp != -1) arp[last_in_arp].start();
    }
  }



  if (breath.value() == 0 && played)    // breath is low enough to stop note
  {
    for (byte i = 0; i < POLYPHONY; i++)
    {
      if (manager.get_note()[i] != 0)
      {
        if (i) MIDI.sendNoteOff(manager.get_note()[i], 0, midi_channel_chords);
        else MIDI.sendNoteOff(manager.get_note()[i], 0, midi_channel);
      }
      //else break;
    }
    played = false;
    stop_played_time = millis();
  }


  if (global_mode == MODE_ARPEGIO || global_mode == MODE_ARPEGIO_RAND) // NEW: to catch that, sometimes, arp stops on a silent note (arp 1, 2, 3, 4)
  {
    if (breath.value() == 0)
    {
      for (byte i = 0; i < 3; i++) arp[i].stop();
    }
  }






  /*********************************
      JOYSTICK
  */
  if (!delta_mode)
  {
    if (joy_X.has_changed()) X_CC.set_value(joy_X.value());
    if (!pitchbend_enable)
    {
      if (joy_Y.has_changed()) Y_CC.set_value(joy_Y.value());
    }
    else PB.set_value(joy_Y.value());
  }
  else
  {
    X_CC.increment_biais(joy_X.value() >> 4);
    if (!pitchbend_enable) Y_CC.increment_biais(joy_Y.value() >> 4);
    else PB.set_value(joy_Y.value());
  }

  X_CC.update();
  if (pitchbend_enable) PB.update();
  else if (Y_CC.update())
  {
    if (Y_CC.get_control() == 72)  // ARP smaller duration time binded to this midi CC
      for (byte i = 0; i < 3; i++) arp[i].set_sustain_scaling(Y_CC.get_value());
  }



  /*
    if (X_CC.has_changed())  MIDI.sendControlChange(X_CC.get_control(), X_CC.get_value(), midi_channel);
    if (!pitchbend) if (Y_CC.has_changed())  MIDI.sendControlChange(Y_CC.get_control(), Y_CC.get_value(), midi_channel);
  */

  /************************
      BREATH
  */
  if (breath.has_changed())
  {
    breath_CC.set_value(breath.MSB());
    if (HQ_breath) breath_LSB_CC.set_value(breath.LSB());
  }
  /*if (played)
    {*/
  breath_CC.update();  // update to see if there is a change
  if (HQ_breath)  breath_LSB_CC.update();
  //}

  // if (breath_CC.has_changed() && played) MIDI.sendControlChange(breath_CC.get_control(), breath_CC.get_value(), midi_channel);







  /****************************
            ARPS
  */
  if (global_mode == MODE_ARPEGIO || global_mode == MODE_ARPEGIO_RAND)
  {
    if (modifier_up.has_been_released())
    {
      arp[0].stop();
      if (modifier_mid.is_pressed() && !arp[1].is_started()) arp[1].start();
      if (modifier_down.is_pressed() && !arp[2].is_started()) arp[2].start();
    }
    if (modifier_mid.has_been_released())
    {
      arp[1].stop();
      if (modifier_up.is_pressed() && !arp[0].is_started()) arp[0].start();
      if (modifier_down.is_pressed() && !arp[2].is_started()) arp[2].start();
    }
    if (modifier_down.has_been_released())
    {
      arp[2].stop();
      if (modifier_up.is_pressed() && !arp[0].is_started()) arp[0].start();
      if (modifier_mid.is_pressed() && !arp[1].is_started()) arp[1].start();
    }

    if (played)  // Just been pressed
    {
      if (modifier_up.has_been_pressed() && !arp[0].is_started())
      {
        arp[0].start();
        arp[1].stop();
        arp[2].stop();
      }
      if (modifier_mid.has_been_pressed() && !arp[1].is_started())
      {
        arp[1].start();
        arp[0].stop();
        arp[2].stop();
      }
      if (modifier_down.has_been_pressed() && !arp[2].is_started())
      {
        arp[2].start();
        arp[0].stop();
        arp[1].stop();
      }
    }
  }

  if (global_mode != MODE_NORMAL)
  {
    if (modifier_sub_up.has_been_released())
    {
      midi_octave += 1;
    }
    if (modifier_sub_down.has_been_released())
    {
      /* if (octave.is_pressed()) midi_octave += 1;
        else*/ midi_octave -= 1;
    }
  }



  /*******************************
      QUICK CHANGE OF PRESET
  */
  if (up_preset.has_been_pressed())
  {
    increment_preset(current_preset_loaded, 1);
    preset_recall(current_preset_loaded);
  }
  if (down_preset.has_been_pressed())
  {
    increment_preset(current_preset_loaded, -1);
    preset_recall(current_preset_loaded);
  }

  /*****************************
        MENU
  */
  if (joy_SW.has_been_released() && !joy_SW.has_been_released_after_long_press())  //else ???
  {
    delta_mode = !delta_mode;
  }
  if (joy_SW.has_been_released_after_long_press())
  {
    joy_SW.reset();
    menu();
  }
  //if (joy_SW.has_been_pressed()) delta_mode = !delta_mode;
  // if (modifier_sub_up.is_pressed() && modifier_sub_down.is_pressed()) menu();


}

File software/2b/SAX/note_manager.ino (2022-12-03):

#include "note_manager.h"
#include "read_shift_reg.h"
#include "button.h"


/*
      Combriat 2018, 2019, 2020
      This file is part of the OS embedded in the e-sax - TES
      This code is under GPL3


      This is the class file for the class managing the mapping between keys and notes, and managing the shift registers
*/






note_manager::note_manager() {
  pinMode(ploadPin, OUTPUT);
  pinMode(clockEnablePin, OUTPUT);
  pinMode(clockPin, OUTPUT);
  pinMode(dataPin, INPUT);
}

byte * note_manager::get_note()
{
  return note;
}

byte * note_manager::get_previous_note()
{
  return previous_note;
}


bool note_manager::update()
{
  unsigned int current_touch = read_shift_regs();

  /* Serial.println(current_touch, BIN);
    delay(100);*/

  // Getting modifying touches
  octave.manual_input( bool(current_touch & 0b000000010000000000000000)); //mouhahahah
  modifier_up.manual_input( bool(current_touch & 0b000000000100000000000000)); //mouhahahahaha
  modifier_mid.manual_input( bool(current_touch & 0b010000000000000000000000));
  modifier_down.manual_input( bool(current_touch & 0b000000000000001000000000));
  modifier_sub_down.manual_input( bool(current_touch & 0b000000000000010000000000));
  modifier_sub_up.manual_input( bool(current_touch & 0b000000100000000000000000));


  down_menu.manual_input(0);
  right_menu.manual_input(0);
  left_menu.manual_input(0);
  up_menu.manual_input(0);
  up_preset.manual_input(0);
  down_preset.manual_input(0);




  for (byte i = 0; i < POLYPHONY; i++)
  {
    previous_note[i] = note[i];
    note[i] = 0;
  }





  /*****************************
    MODE NORMAL: like a real sax, no more, no less
  */

  if (global_mode == MODE_NORMAL)
  {

    unsigned int current_touch_no_mod = current_touch & (0b111111101101111111111111);  //haha (removing modifiers) and dead valves (first right hand)

   /* Serial.println(current_touch_no_mod);
    delay(100);*/

    switch (current_touch_no_mod)
    {


      case 1048576:   //A# bass
        note[0] = 46;;
        break;

      case 1048580:
        note[0] = 47;  //B
        break;

      case 1048581:  //C bass
        note[0] = 48;
        break;

      /* case 2622532:  //C bass (G#)
         note[0] = 48;
         break;*/

      case 1048589: //C# bass
        note[0] = 49;
        break;

      case 1050629: //D
        note[0] = 50;
        break;

      /* case 2622540: //D  (G#)
         note[0] = 50;
         break;*/

      case 1050645: //D#
        note[0] = 51;
        break;

      /* case 2638924: //D# (G#)
         note[0] = 51;
         break;*/

      case 1083397: //E
        note[0] = 52;
        break;

      /*case 3671116: //E  (G#)
        note[0] = 52;
        break;*/

      case 9472005: //F
        note[0] = 53;
        break;

      /*case 3675212: //F (G#)
        note[0] = 53;
        break;*/

      case 1083399: //F#
        note[0] = 54;
        break;

      /* case 3671132: //F#  (G#)
         note[0] = 54;
         break;*/

      case 9473029: //F# (sub down)
        note[0] = 54;
        break;

      /* case 3675244: //F# (sub down) (G#)
         note[0] = 54;
         break;*/

      case 9472007: //G
        note[0] = 55;
        break;

      case 9996295: //G#
        note[0] = 56;
        break;

      case 9996303: //G# (C#)
        note[0] = 56;
        break;

      /* case 10004495: //G# (C#)
         note[0] = 56;
         break;*/

      case 9996294: //G# (B)
        note[0] = 56;
        break;

      /* case 3675164: //G# (B)
         note[0] = 56;
         break;*/

      case 9996290: //G#  (Bb)
        note[0] = 56;
        break;

      /* case 10786468: //G#  (Bb)
         note[0] = 56;
         break;*/

      case 9472135: //A
        note[0] = 57;
        break;

      case 9472133: //A (F)
        note[0] = 57;
        break;

      case 1083527: //A (F#)
        note[0] = 57;
        break;

      case 1083525: //A (E)
        note[0] = 57;
        break;

      case 1050757: //A (D)
        note[0] = 57;
        break;

      case 1050773: //A (D#)
        note[0] = 57;
        break;

      case 1048709: //A (C)
        note[0] = 57;
        break;

      case 9734279: //A# (std)
        note[0] = 58;
        break;

      case 9472647: //A# (mod down)
        note[0] = 58;
        break;

      case 9734277: //A# (F)
        note[0] = 58;
        break;

      case 1345671: //A# (F#)
        note[0] = 58;
        break;



      case 1345925: //A# (E)
        note[0] = 58;
        break;

      case 1345669: //A# (E)
        note[0] = 58;
        break;


      case 1313157: //A# (D)
        note[0] = 58;
        break;

      case 1312901: //A# (D)
        note[0] = 58;
        break;

      case 9734407: //A# (C)
        note[0] = 58;
        break;

      case 1312917: //A# (D#)
        note[0] = 58;
        break;

      /* case 8794912: //A# (D)
         note[0] = 58;
         break;*/

      /* case 3675736: //A# (G)
         note[0] = 58;
         break;*/

      case 9734535: //B
        note[0] = 59;
        left_menu.manual_input(1);
        break;

      case 11569287: //C
        note[0] = 60;
        right_menu.manual_input(1);
        break;

      case 11569159: //C (G)
        note[0] = 60;
        break;

      case 11569285: //C (F)
        note[0] = 60;
        break;

      case 11569157: //C (F (G)))
        note[0] = 60;
        break;

      case 3180679: //C (F#)
        note[0] = 60;
        break;

      case 3180551: //C (F# (G))
        note[0] = 60;
        break;

      case 3180677: //C (E)
        note[0] = 60;
        break;

      case 3180549: //C (E (G))
        note[0] = 60;
        break;

      case 3147909: //C (D)
        note[0] = 60;
        break;

      case 3147781: //C (D (G))
        note[0] = 60;
        break;

      case 3147925: //C (D#)
        note[0] = 60;
        break;

      case 3147797: //C (D# (G))
        note[0] = 60;
        break;

      case 13928839: //C (mod mid)
        note[0] = 60;
        break;

      /*  case 15754009: //C
          note[0] = 60;
          break;
      */

      case 11831687: //C#
        note[0] = 61;
        break;

      /*  case 8828592: //C#
          note[0] = 61;
          break;*/

      case 11831429: //C# (F)
        up_menu.manual_input(1);
        note[0] = 61;
        break;

      /* case 8796080: //C# (F)
         note[0] = 61;
         break;*/

      /* case 8827824: //C# (F#)
         note[0] = 61;
         break;*/

      case 3442823: //C# (F#)
        down_menu.manual_input(1);
        note[0] = 61;
        break;



      case 3442821: //C# (E)
        note[0] = 61;
        break;

      /*  case 8795056: //C# (E)
          note[0] = 61;
          break;
      */


      case 3410053: //C# (D)
        note[0] = 61;
        break;

      /*  case 8794928: //C# (D)
          note[0] = 61;
          break;*/

      case 3410069: //C# (D#)
        note[0] = 61;
        break;
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

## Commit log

2020-02-26 Added hardware o
    [SAX_2.dsn, SAX_2.kicad_pcb, SAX_2.sch]
2020-03-02 Moved into a dir properly nammed for Arduino
2020-04-14 Corrected tap tempo, completed chord_mode
    [SAX.ino, chord.ino, menu.ino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]
2020-04-16 Added chords and one arp. Corrected wrong logic for both
    [SAX.ino, arpegio_mono.ino, menu.ino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]
2020-04-18 Added a time limiter for MIDI NOTE ON/OFF to avoid jamming
    [SAX.ino]
2020-04-18 Corrected timing issue with CHORD: up, mid and down now have null response time
    [SAX.ino, menu.ino, note_manager.ino]
2020-04-19 Corrected wrong logic in button class
    [SAX.ino, button.ino]
2020-04-19 Corrected a wrong pointer on ARP, was messing random stuff. Optimized tap_tempo in the mean time
    [SAX.ino, button.ino, menu.ino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]
2020-05-19 Fixed chords, broken by previous commits
    [SAX.ino]
2020-05-28 Fixed arpegio, added random arpegiator
    [SAX.ino, arpegio_mono.ino, menu.ino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]
2020-05-30 Added alternate fingerings, improved random arp
2020-06-05 Added and implemented Normal mode. Old normal mode is now EWI mode. Corrected a pad, which changed a few fingerings
    [SAX.ino, menu.ino, note_manager.ino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]
2020-07-06 Corrected small bug for interaction between chords and octaves (to be tested)
    [note_manager.ino]
2020-08-23 Added v2.1, allowing to measure battery pourcentage
    [SAX_2.dsn, SAX_2.kicad_pcb, SAX_2.sch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]
2020-08-30 Cleaned Pcb, added a comment to test in code
    [SAX_2.dsn, SAX_2.kicad_pcb, SAX_2.sch]
2020-09-01 Added threshold in NoteOn, to avoid glitches between 0 and 1 volume breath values
    [SAX.ino]
2020-11-15 Adapted code for inverted joysticks
    [SAX.ino, analog_input.ino]
2020-11-24 Fingerings sax2
2020-11-25 Added interruptCapsense prelim
2020-11-28 Fixed wrong touches. Batt measurement OK
    [SAX.ino, menu.ino, note_manager.ino]
2021-01-16 Added spaces in PCB
    [SAX_2.dsn, SAX_2.kicad_pcb, SAX_2.sch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]
2021-01-20 Improved fab layer
    [SAX_2.kicad_pcb, SAX_2.sch]
2021-04-04 Added reset function to button
    [button.ino]
2021-04-04 Corrected recall of presets
    [presets.ino]
2021-04-04 Added not vely convincing battery level check
2021-05-03 Added shortcut for presets
    [menu.ino]
2021-05-04 New version of stm32 has correct serial numbers...
    [SAX.ino]
2021-05-05 Corrected wrong scaling when retreiving presets
    [presets.ino]
2021-05-16 Added a kicad project
2021-06-01 Adapted the code to new class, fixed minor issues
    [SAX.ino, menu.ino, presets.ino]
2021-08-22 Added calibration for the joystick max value
2021-08-22 MIDI CC for HQ breath correct
    [SAX.ino, menu.ino]
2021-08-25 Fixed chords not playing at max vol
    [SAX.ino]
2021-09-20 Correction of midi_CC delay
    [SAX.ino, midi_cc.ino]
2021-12-10 Added v3 - Fast screen (SPI) and sourceable Teensy based
    [SAX_3.dsn, SAX_3.kicad_pcb, SAX_3.sch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]
2021-12-13 Updated PCB with correct JST connectors, optimized PCB
    [SAX_3.kicad_pcb, SAX_3.sch]
2021-12-14 Updated pcb
    [SAX_3.kicad_pcb]
2022-02-20 Added v3d1: better footprnts
    [SAX_3.dsn, SAX_3.kicad_pcb, SAX_3.sch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]
2022-02-20 Migrated to kicad v6
    [SAX_3.kicad_pcb, SAX_3.kicad_sch]
2022-05-19 Fixed drift in analogInput
    [SAX_3.kicad_pcb]
2022-05-22 Initial commit of v3d2
    [SAX_3.kicad_pcb, SAX_3.kicad_sch, SAX_3.sch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]
2022-05-30 Working PCB, improvments on breath input filtering
    [SAX_3.kicad_pcb, SAX_3.kicad_sch]
2022-09-18 Note bindings for sax mode
    [SAX.ino, menu.ino, note_manager.ino]
2022-09-18 Added minimal class for LEDstrand
2022-09-18 Included LEDstrand class in main
2022-09-19 Fixed rollback in menu, attempt for strand effect on startup
    [SAX.ino, menu.ino]
2022-09-20 Added LED startup sequence
2022-10-02 Corrected overflow on joystick
    [SAX.ino, midi_cc.ino]
2022-10-02 Added a mode to remove the LED strand action
2022-10-05 Corrected arp stopping and starting for -255 containing ARP, small opti on 14bits breath
    [SAX.ino, curved_analog_input.ino]
2022-11-18 Added better battery estimate and visual clue
2022-11-20 Corrected overflow in sax3
    [SAX.ino, note_manager.ino]
2022-11-20 Corrected keying on sax4
    [SAX.ino, note_manager.ino]
2022-12-03 Added some fingerings
2023-03-22 Added joystick dead zone to remove small drift on teensy4
    [SAX.ino, analog_input.ino]
2023-10-01 Started V( hardware sax, with Pico platform. Added footprint for joystick
    [v4_pico.dsn, v4_pico.kicad_pcb, v4_pico.kicad_sch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]
2023-10-02 Added multiswitch footprint and update FJ08K
2023-10-03 Started porting to pico, LED strip and Joystick moved
    [v4_pico.kicad_sch]
2023-10-03 Added switch on PCB for on/off, neck updated
    [v4_pico.kicad_sch]
2023-10-04 Wired screen and shift register v4
    [v4_pico.kicad_sch]
2023-10-25 Added ADC component for battery check
    [SAX_3.kicad_sch, v4_pico.kicad_sch]
2023-11-05 Schematic and assign for saxo pico
    [v4_pico.kicad_sch]
2023-11-05 Corrected scheme for DRC«
    [v4_pico.kicad_sch]
2023-11-05 Moved adc and screen to same bus
    [v4_pico.kicad_sch]
2023-11-05 Updated footprints
    [v4_pico.kicad_sch]
2023-11-05 Adapted and tested shift registers on SPI1
    [v4_pico.kicad_sch]
2023-11-06 Started PCB
    [v4_pico.kicad_pcb, v4_pico.kicad_sch]
2023-11-06 Work on PCB
    [v4_pico.kicad_pcb, v4_pico.kicad_sch]
2023-11-06 Trying to place everythin on pcb...
    [v4_pico.kicad_pcb, v4_pico.kicad_sch]
2023-11-07 Initial routing
    [v4_pico.dsn, v4_pico.kicad_pcb, v4_pico.kicad_sch]
2023-11-09 Improved silk
    [v4_pico.kicad_pcb, v4_pico.kicad_sch]
2023-11-09 Check on courtyarb, placing
    [v4_pico.kicad_pcb, v4_pico.kicad_sch]
2023-11-09 Trying to make room
    [v4_pico.kicad_pcb]
2023-11-11 PCB cured and routed
    [v4_pico.kicad_pcb, v4_pico.kicad_sch]
2023-11-13 Added Gerber
    [v4_pico-B_Cu.gbl, v4_pico-B_Mask.gbs, v4_pico-B_Paste.gbp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]
2023-11-29 Correction on v4
    [v4d1_pico.kicad_pcb, v4d1_pico.kicad_sch]
2025-03-24 Updated PCB with bite sensor
    [v4_pico.kicad_sch, v4d1_pico.kicad_sch]
2025-04-01 v4d2 of eSax. EEPROM, beak pressure. Schema only
    [v4d2_pico.kicad_pcb, v4d2_pico.kicad_sch]
2025-04-02 Routed PCB
    [v4d2_pico.kicad_pcb]
2025-04-06 Updated PCB, gerber export
    [v4d2_pico-B_Cu.gbl, v4d2_pico-B_Mask.gbs, v4d2_pico-B_Paste.gbp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]
2025-04-08 Updated PCB for v4.2
    [v4d2_pico-B_Cu.gbl, v4d2_pico-B_Mask.gbs, v4d2_pico-B_Paste.gbp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]
2025-04-16 Small fix on beak pcb
    [SAX_4.dsn, v4d3_pico.kicad_pcb, v4d3_pico.kicad_sch]
